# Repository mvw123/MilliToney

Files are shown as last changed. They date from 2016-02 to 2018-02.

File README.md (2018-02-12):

MilliToney Board 
================

Milliohmeter and tone generator
Used for measuring resistancefrom approx 1m Ohm to 1 ohm and for finding short circuits by generating a tone. 
Design files are in Eagle (free version).

CAD A - [Work In progress]
=====================

Schematic Done. 
Part values to be decided.
CAD A ordered from Elecrow. $15.00 for 10 off. 2016Jan16
PCBs arrived. 
Circuit not functioning fully. Needs the V-F circuit correcting. Also the milliohmeter is not as accurate as expected.
See issues list for details.

MVW

www.guvvy.co.uk

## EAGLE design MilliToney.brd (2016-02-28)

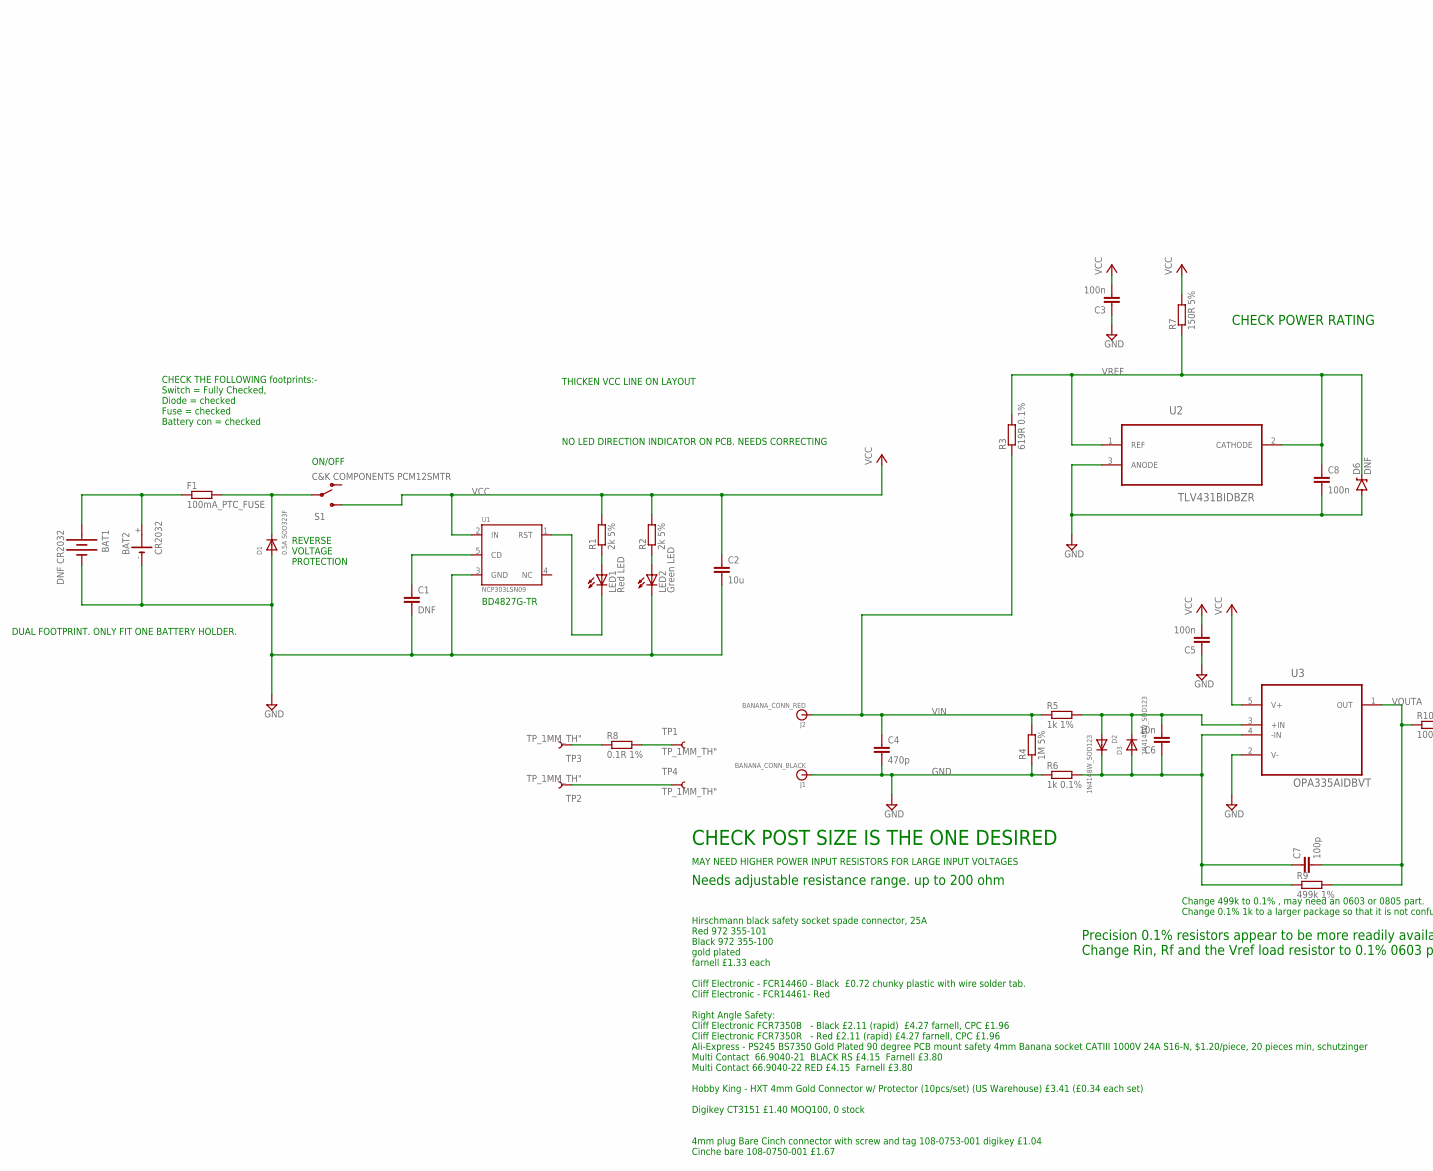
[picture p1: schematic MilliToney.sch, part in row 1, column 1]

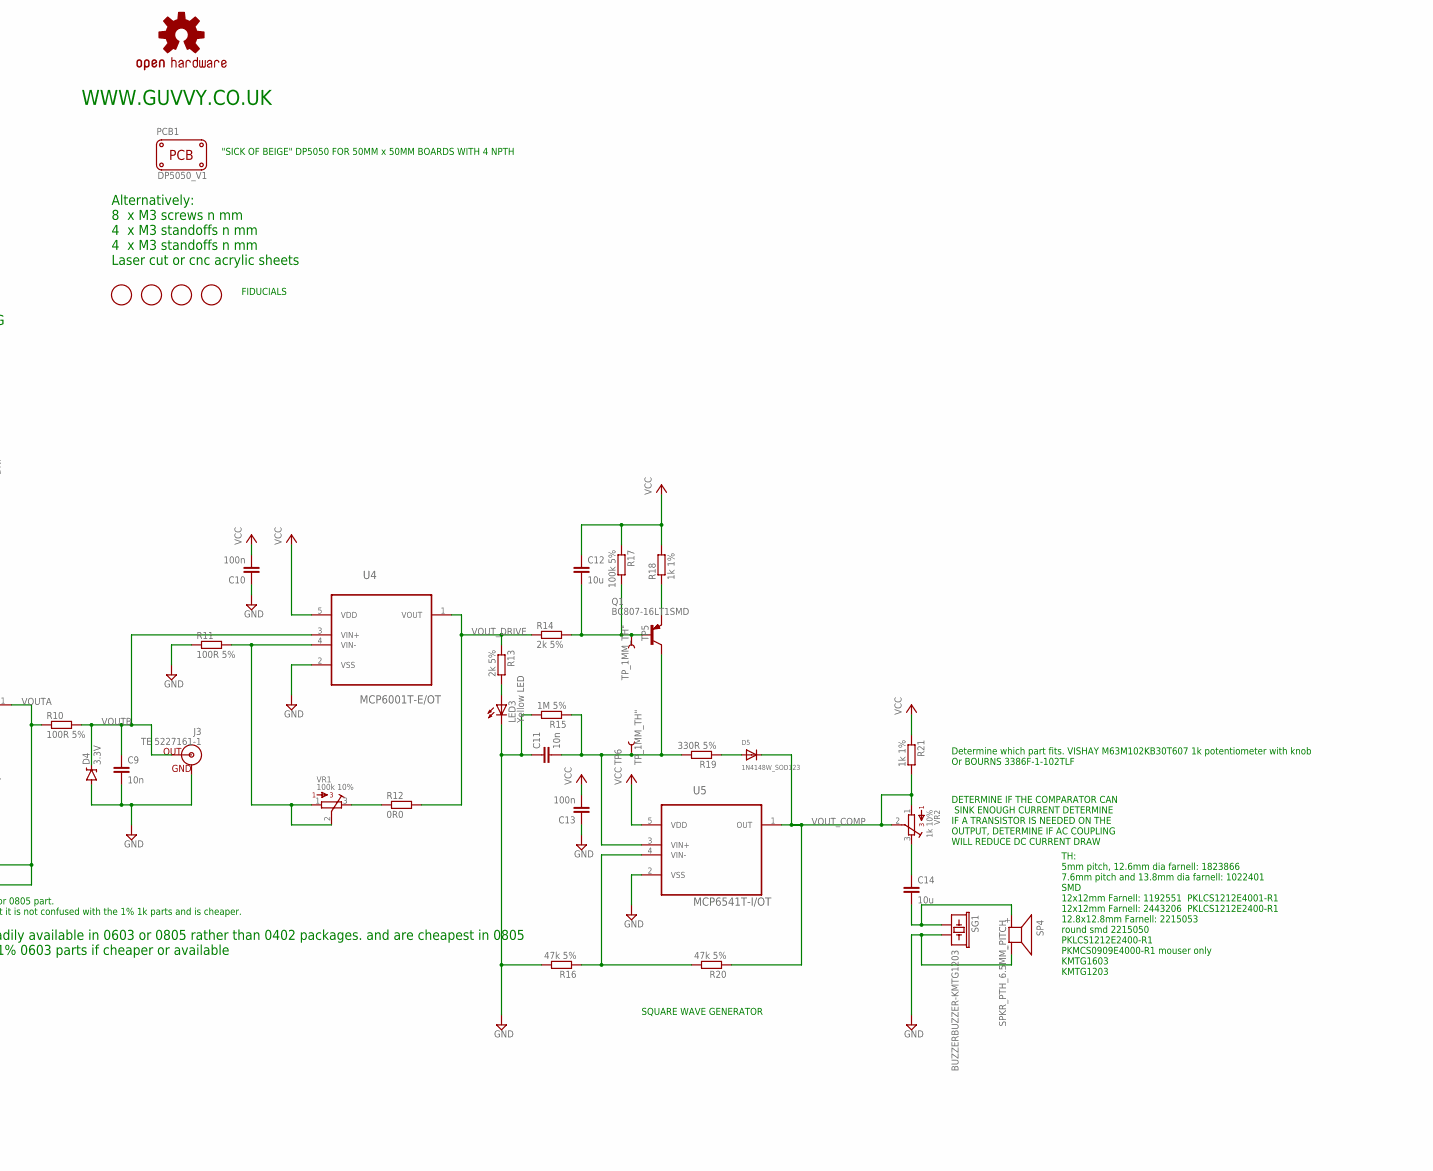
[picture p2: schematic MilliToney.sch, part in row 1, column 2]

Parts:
BAT1: DNF CR2032; BATTERY_20MM_PTH_COMPACT
BAT2: CR2032; KZH20SMD; MPN SMTU 2032-LF
C1: DNF; C0402K
C2, C12: 10u; C0603; MPN GRM188R61A106ME69D
C3, C5, C8, C10, C13: 100n; C0402K; MPN MC0402X104K100CT
C4: 470p; C0402K
C6, C9, C11: 10n; C0402K
C7: 100p; C0402K
C14: 10u; C0603K; MPN GRM188R61A106ME69D
D1: 0.5A SOD323F; SOD-323F; MPN PMEG3010EJ,115
D2, D3, D5: 1N4148W_SOD123; SOD-123FL; MPN 1N4148W
D4: 3.3V; SOD-323
D6: DNF; SOD-323
F1: 100mA_PTC_FUSE; R0805; MPN MF-PSMF010X-2
FID1, FID2, FID3, FID4: FIDUCIAL; FIDUCIAL_1MM
J1: BANANA_CONN_BLACK; BANANA_CONN; MPN FCR14460
J2: BANANA_CONN_RED; BANANA_CONN; MPN FCR14461
J3: TE 5227161-1; BNC; MPN 5227161-1
LED1: Red LED; SML0603; MPN KP-1608SURCK
LED2: Green LED; SML0603; MPN KP-1608CGCK
LED3: Yellow LED; SML0603; MPN KP-1608SYCK
LOGO1: OSHW-LOGOL; OSHW-LOGO-L
PCB1: PCB_DP_SQUARE-5X5; DP5050_V1
Q1: BC807-16LT1SMD; SOT23-BEC; MPN BC807-16LT1G
R1, R2, R13, R14: 2k 5%; R0402
R3: 619R 0.1%; R0402; MPN CPF0402B619RE1
R4, R15: 1M 5%; R0402
R5, R18, R21: 1k 1%; R0402
R6: 1k 0.1%; R0402; MPN PCF0402-R-1K-B-T1.
R7: 150R 5%; R0402
R8: 0.1R 1%; R0603; MPN ERJ3RSFR10V
R9: 499k 1%; R0402; MPN ERJ3EKF4993V
R10, R11: 100R 5%; R0402
R12: 0R0; R0402
R16, R20: 47k 5%; R0402
R17: 100k 5%; R0402
R19: 330R 5%; R0402
S1: C&K COMPONENTS PCM12SMTR; SWITCH-SPST-SMD-A; MPN PCM12SMTR
SG1: BUZZERBUZZER-KMTG1203; BUZZER-KMTG1203; MPN KMTG1203
SP4: SPKR_PTH_6.5MM_PITCH; KSS1201
TP1, TP2, TP3, TP4, TP5, TP6: TP_1MM_TH"; TP_1MM_TH
U1: NCP303LSN09; SOT23-5; MPN BD4827G-TR
U2: TLV431BIDBZR; SOT95P237X112-3N; MPN TLV431BCDBZTG4
U3: OPA335AIDBVT; SOT95P280X145-5N
U4: MCP6001T-E/OT; SOT95P270X145-5N
U5: MCP6541T-I/OT; SOT95P290X145-5N
VR1: 100k 10%; 3386F; MPN 3386F-1-104TLF
VR2: 1k 10%; 3386F; MPN 3386F-1-102TLF

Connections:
GND: BAT1.2 (-), BAT2.-, C1.2, C2.2, C3.1, C4.2, C5.1, C8.2, C9.2, C10.1, C11.1, C13.1, D1.A, D4.A, D6.A, J1.P$1, J3.GND, LED2.C, LED3.C, R4.1, R6.1, R11.1, R15.2, R16.2, SG1.2, SP4.- (2), U1.3 (GND), U2.3 (ANODE), U3.2 (V-), U4.2 (VSS), U5.2 (VSS)
unnamed: BAT1.1 (+), BAT2.+, F1.1
unnamed: C14.2, SG1.1, SP4.+ (1)
unnamed: R8.1, TP3.P$1
unnamed: C6.2, D2.A, D3.C, R5.2, U3.3 (+IN)
unnamed: TP2.P$1, TP4.P$1
unnamed: D5.A, R19.1
unnamed: C6.1, C7.1, D2.C, D3.A, R6.2, R9.1, U3.4 (-IN)
unnamed: R12.1, VR1.3
unnamed: R11.2, U4.4 (VIN-), VR1.1, VR1.2
unnamed: LED1.C, U1.1 (RST)
unnamed: C12.2, Q1.B, R14.2, R17.2, TP5.P$1
unnamed: Q1.E, R18.1
unnamed: D1.C, F1.2, S1.2
unnamed: C1.1, U1.5 (CD)
unnamed: R16.1, R20.2, U5.4 (VIN-)
unnamed: C14.1, VR2.3
unnamed: LED3.A, R13.2
unnamed: C11.2, Q1.C, R15.1, R19.2, TP6.P$1, U5.3 (VIN+)
unnamed: LED1.A, R1.1
unnamed: R8.2, TP1.P$1
unnamed: LED2.A, R2.1
VCC: C2.1, C3.2, C5.2, C10.2, C12.1, C13.2, R1.2, R2.2, R7.2, R17.1, R18.2, R21.1, S1.3 (S), U1.2 (IN), U3.5 (V+), U4.5 (VDD), U5.5 (VDD)
VIN: C4.1, J2.P$1, R3.1, R4.2, R5.1
VOUTA: C7.2, R9.2, R10.1, U3.1 (OUT)
VOUTB: C9.1, D4.C, J3.S (OUT), R10.2, U4.3 (VIN+)
VOUT_COMP: D5.C, R20.1, R21.2, U5.1 (OUT), VR2.1, VR2.2
VOUT_DRIVE: R12.2, R13.1, R14.1, U4.1 (VOUT)
VREF: C8.1, D6.C, R3.2, R7.1, U2.1 (REF), U2.2 (CATHODE)

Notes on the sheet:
REVERSE VOLTAGE PROTECTION
ON/OFF
WWW.GUVVY.CO.UK
DETERMINE IF THE COMPARATOR CAN SINK ENOUGH CURRENT DETERMINE IF A TRANSISTOR IS NEEDED ON THE OUTPUT, DETERMINE IF AC COUPLING WILL REDUCE DC CURRENT DRAW
CHECK THE FOLLOWING footprints:- Switch = Fully Checked, Diode = checked Fuse = checked Battery con = checked
MAY NEED HIGHER POWER INPUT RESISTORS FOR LARGE INPUT VOLTAGES
BD4827G-TR
SQUARE WAVE GENERATOR
"SICK OF BEIGE" DP5050 FOR 50MM x 50MM BOARDS WITH 4 NPTH
FIDUCIALS
DUAL FOOTPRINT. ONLY FIT ONE BATTERY HOLDER.
CHECK POST SIZE IS THE ONE DESIRED
Hirschmann black safety socket spade connector, 25A Red 972 355-101 Black 972 355-100 gold plated farnell £1.33 each Cliff Electronic - FCR14460 - Black £0.72 chunky plastic with wire solder tab. Cliff Electronic - FCR14461- Red Right Angle Safety: Cliff Electronic FCR7350B - Black £2.11 (rapid) £4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
Needs adjustable resistance range. up to 200 ohm
TH: 5mm pitch, 12.6mm dia farnell: 1823866 7.6mm pitch and 13.8mm dia farnell: 1022401 SMD 12x12mm Farnell: 1192551 PKLCS1212E4001-R1 12x12mm Farnell: 2443206 PKLCS1212E2400-R1 12.8x12.8mm Farnell: 2215053 round smd 2215050 PKLCS1212E2400-R1 PKMCS0909E4000-R1 mouser only KMTG1603 KMTG1203
Alternatively: 8 x M3 screws n mm 4 x M3 standoffs n mm 4 x M3 standoffs n mm Laser cut or cnc acrylic sheets
Precision 0.1% resistors appear to be more readily available in 0603 or 0805 rather than 0402 packages. and are cheapest in 0805 Change Rin, Rf and the Vref load resistor to 0.1% 0603 parts if cheaper or available
CHECK POWER RATING
Determine which part fits. VISHAY M63M102KB30T607 1k potentiometer with knob Or BOURNS 3386F-1-102TLF
NO LED DIRECTION INDICATOR ON PCB. NEEDS CORRECTING
THICKEN VCC LINE ON LAYOUT
Change 499k to 0.1% , may need an 0603 or 0805 part. Change 0.1% 1k to a larger package so that it is not confused with the 1% 1k parts and is cheaper.

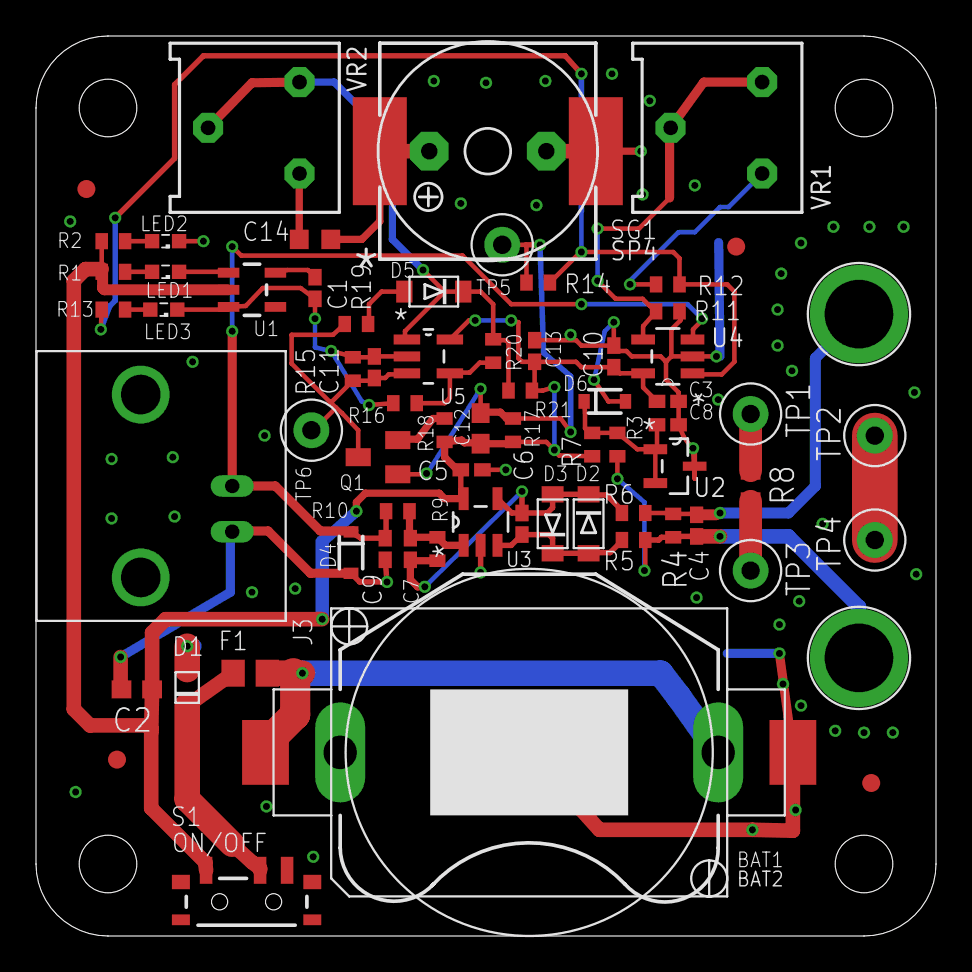
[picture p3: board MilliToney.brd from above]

Board: 2 copper layers, 50.0 x 50.0 mm, 73 parts (1 on the bottom side), 29 nets.

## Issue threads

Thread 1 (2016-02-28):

CAD A issues

mvw123, 2016-02-28:
CAD A issues

1. 4mm connector attachment needs improvement. change to 4mm male and female hand solder parts.
2. Consider splitting the design into milliohmeter and seperate attachment for short circuit finder. Stackable, as first envisaged!
3. Also consider changing to all through hole parts
4. Precision 0.1% resistors are cheaper and more readily available in larger sizes. 0603, 0805
5. Input resistors need to be larger for protection against high voltages.
6. Cheaper switches which appear to be TH types rather than SMD
7. consider ranges for the unput resistance
8. ESD protection on output - zener is going to be blown if placed into a circuit with a voltage on its output
9. Alternative to OPA335
10. Write up a references list for sources for the design.
11. battery output voltage dropped below 2.7v due to the load, address in circuit or with a new battery.
12. output drive probably needs a transistor.
13. battery won't last long with this current drain.
14. change the potentiometers  - possible use the wheel types for side adjustment
15. casework design
16. PCB colour didn't work out.
17. Ref Des text isn't very clear and isn't the same size.
18. potentiometers cases were not set for the parts obtained. though issue may be a mute point since they may be changing.
19. Casework needs studying to see if its suitable when design is finalised.
20. Where to manufacture. possibly elecrow.
21. some of the routing wasn't ideal.
22. power routing needs improving
23. outer edge needs ground ring to stop ESD issues in an acrylic top/bottom case.

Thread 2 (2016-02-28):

Battery change

mvw123, 2016-02-28:
CR2032 batteries are not suitable in a system drawing nearly 25mA. load current needs to be vastly reduced or battery type improved.

CR2032 datasheet
Continuous quoted at 0.19mA, 1263hrs from 2.9v down to 2v. (15k load) 900hrs to 2.8v
40 ohm * 0.02A = 0.8v drop.
http://data.energizer.com/PDFs/cr2032.pdf
Classification: "Lithium Coin"
Chemical System: Lithium / Manganese Dioxide (Li/MnO2)
Designation: ANSI / NEDA-5004LC, IEC-CR2032
Nominal Voltage: 3.0 Volts
Typical Capacity: 240 mAh (to 2.0 volts) (Rated at 15K ohms at 21°C)
Typical Weight: 3.0 grams (0.10 oz.)
Typical Volume: 1.0 cubic centimeters (0.06 cubic inch)
Typical IR: 10,000 - 40,000 m Ω
Max Rev Charge: 1 microampere
Energy Density: 198 milliwatt hr/g, 653 milliwatt hr/cc
Typical Li Content: 0.109 grams (0.0038 oz.)
UL Recognized: MH29980
Operating Temp:-30C to 60C
Self Discharge: ~1% / year

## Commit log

2015-10-25 First Commit
    Rough schematic, not completed.
    [MilliToney.brd, MilliToney.sch]
2016-01-10 Committing latest updates
    Committing latest updates. dual footprints buzzer and battery, updated
    other parts. added 5x5 footprint for board
    [MilliToney.brd, MilliToney.sch]
2016-01-15 Minor updates
    Minor Updates
    [MilliToney.brd, MilliToney.sch]
2016-01-15 CAD A Release Version
    CAD A Release Version
    Moved battery inboard requiring moving of various components
    [MilliToney.brd, MilliToney.sch]
2016-01-26 minor movement on the schematic
    minor movement on the schematic
    [MilliToney.brd, MilliToney.sch]
2016-02-21 Updated part values and part number
    Updated part values and part number
    [MilliToney.brd, MilliToney.sch]
2016-02-28 updated layout and parts
    updated layout and parts
    [MilliToney.brd, MilliToney.sch]
2017-09-25 minor updates
    [MilliToney.sch]

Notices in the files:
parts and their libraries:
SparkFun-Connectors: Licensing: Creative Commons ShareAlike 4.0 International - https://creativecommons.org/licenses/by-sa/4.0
